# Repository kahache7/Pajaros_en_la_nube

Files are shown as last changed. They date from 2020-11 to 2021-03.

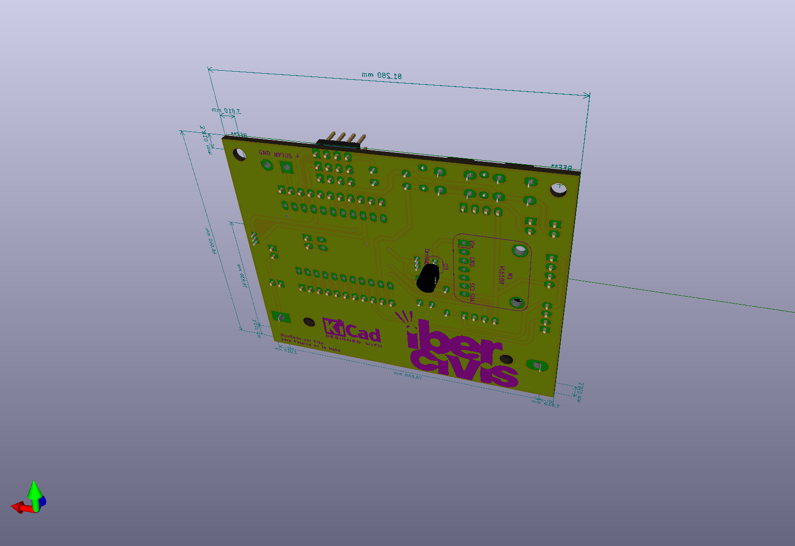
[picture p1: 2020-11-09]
Electronica/Fotos/AdaptaddorCubeCell3.png

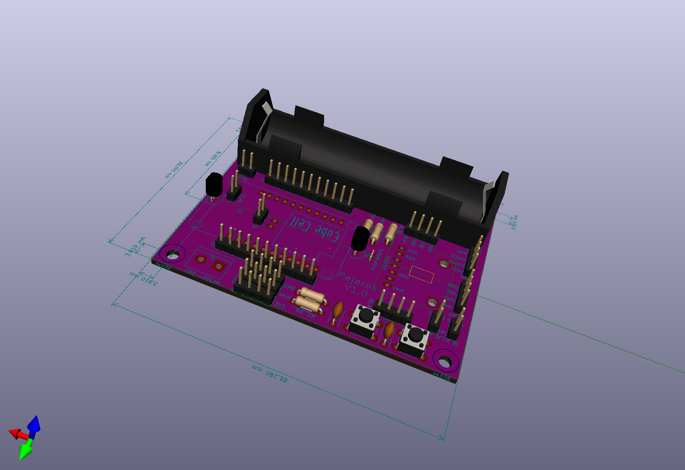
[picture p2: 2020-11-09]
Electronica/Fotos/AdaptaddorCubeCell.png

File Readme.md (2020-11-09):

# Pájaros en la Nube

El proyecto Pájaros en la Nube tiene como objetivo monitorizar la fauna insectívora en todo el país, a través del desarrollo de un proyecto multidisciplinar que abarca diversas áreas del conocimiento científico y tecnológico, e involucrando a miles de estudiantes de centros de educación de primaria y secundaria.

Temas como la conservación de la biodiversidad, la ornitología, el internet de las cosas (IoT, por sus siglas en Inglés, Internet of Things), la computación en la nube, arduino, programación, matemáticas, meteorología y ciencia ciudadana (CC) se unen de forma consistente en un único proyecto.

Fundación Ibercivis FeCyT

### Mecánica del Proyecto
Durante el curso 2020/21 se colaborará con 100 centros educativos de todo el país que recibirán -sin coste alguno- los materiales para ensamblar y sensorizar una caseta de pájaros que, tras su montaje, será colocada en las inmedicaiones del centro.

La observación de esta caseta y los datos que entregarán sus sensores –presencia de animales en ella y temperatura– servirá para que los alumnos conozcan y estudien la fauna insectívora que les rodea -principalmente aves, pero también pequeños reptiles, murciélagos…-.

Además, como parte del trabajo inicial de montaje de la caseta, los alumnos aprenderán a programar en arduino para controlar sus sensores, y adquirirán nociones de física, matemáticas o meteorología.

El envío de datos desde la caseta al aula se hará a través de la tecnología LoRaWAN diseñada específicamente para dispositivos de bajo consumo de alimentación, que operan en redes de alcance local, regional, nacionales o globales. Este montaje convierte a la caseta en un dispositivo conectado al Internet de las Cosas (IOT).

* Start object:
```void begin(pinRX,pinTX);```

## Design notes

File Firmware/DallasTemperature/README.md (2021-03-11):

Modificaciones para el fichero DallasTemperature.cpp de la version 3.9

Sustituir yield() por delay(0) para que compile bien en cubecell

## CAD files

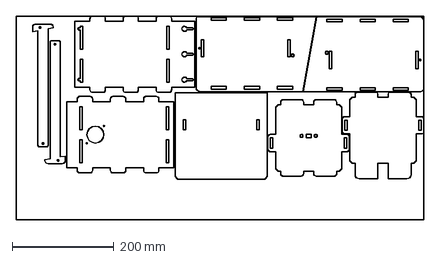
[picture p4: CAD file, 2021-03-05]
Caseta/laser_5mm_v3.dxf
800.0 x 400.2 mm

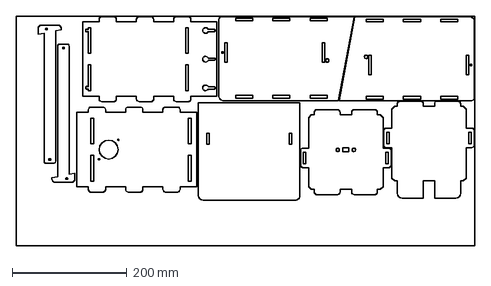
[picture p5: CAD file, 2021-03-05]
Caseta/laser_4.5mm_v3_zgz.dxf
800.0 x 400.0 mm

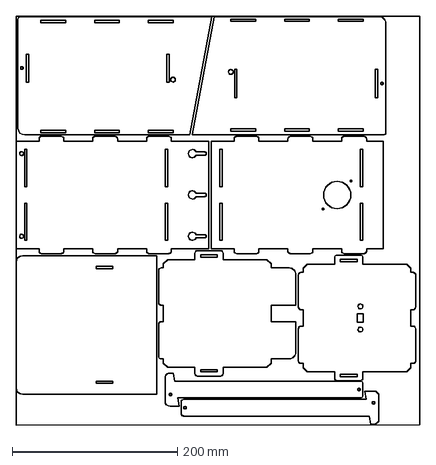
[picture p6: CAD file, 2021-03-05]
Caseta/laser_2.9mm_v3.dxf
488.3 x 494.4 mm

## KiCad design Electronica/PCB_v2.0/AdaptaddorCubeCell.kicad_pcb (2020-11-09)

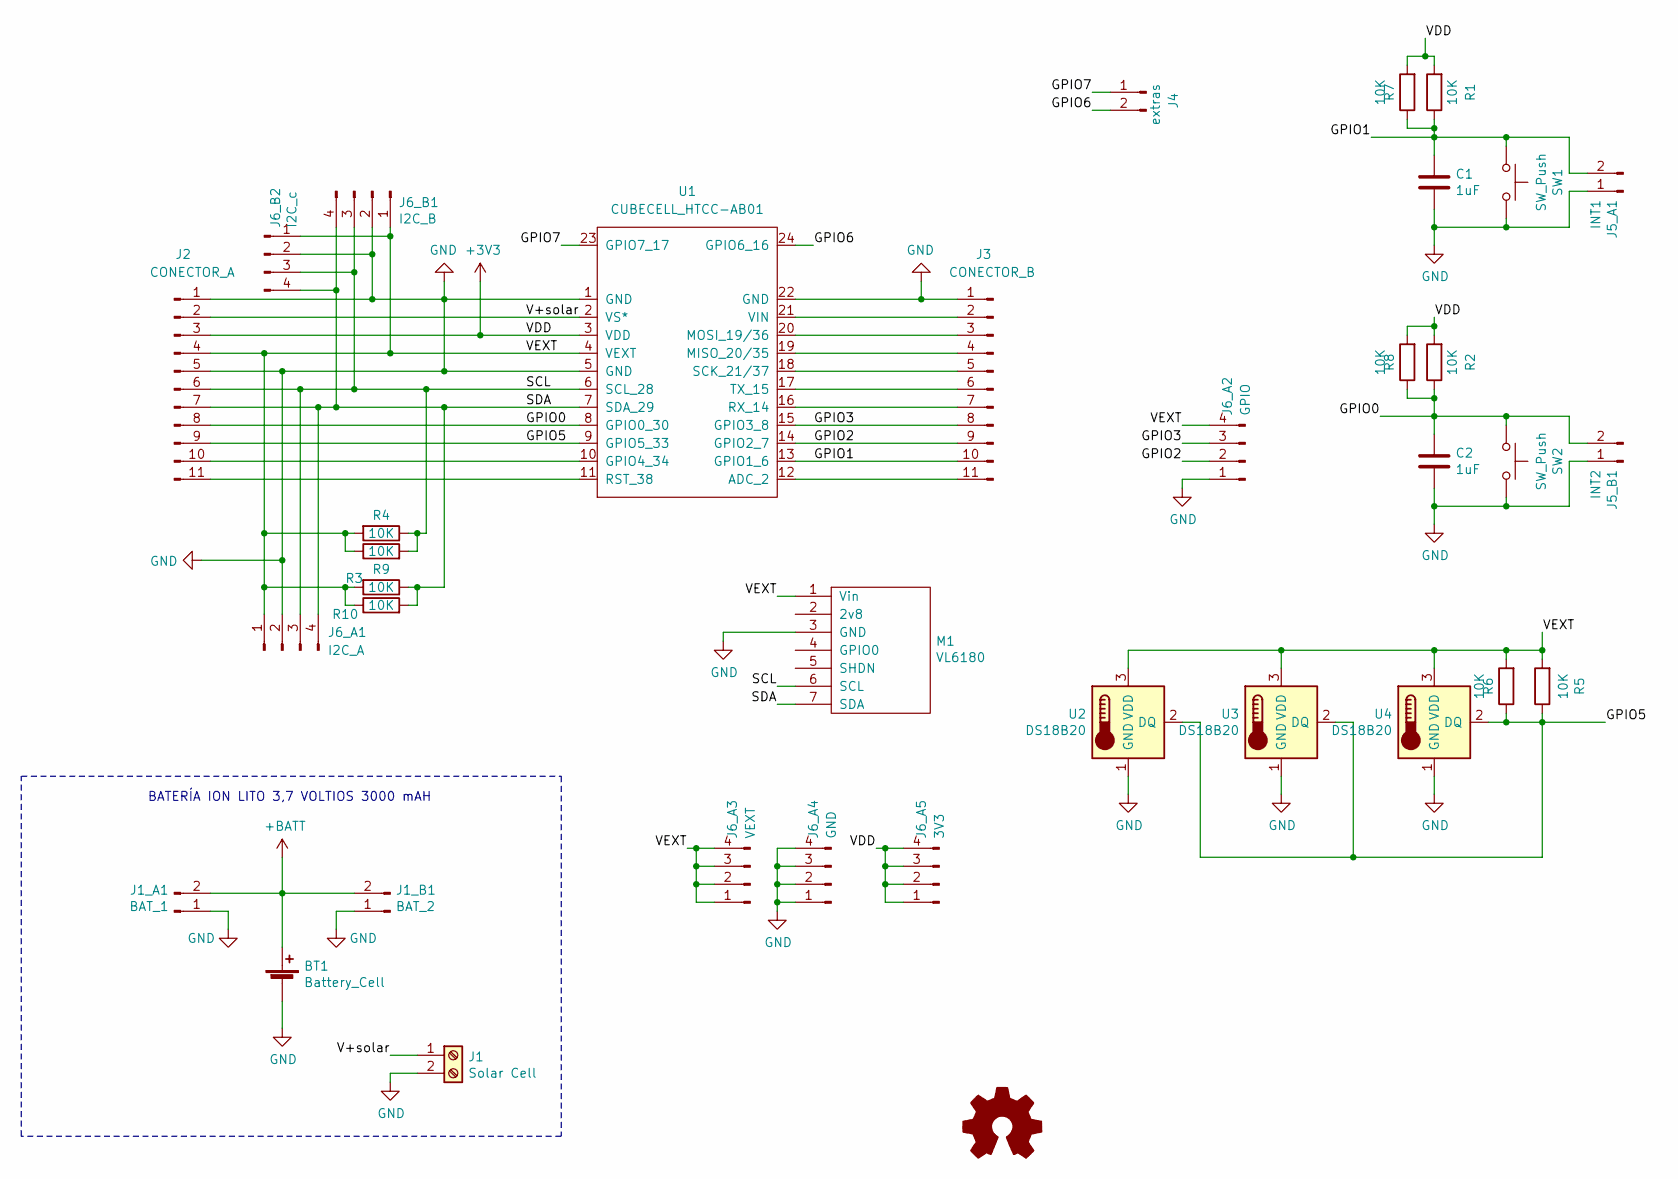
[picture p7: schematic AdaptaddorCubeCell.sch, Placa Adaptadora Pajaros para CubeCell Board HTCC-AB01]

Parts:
BT1: Battery_Cell; BatteryHolder_MPD_BH-18650-PC2
C1, C2: 1uF; C_Disc_D5.0mm_W2.5mm_P5.00mm
J1: Solar Cell; TerminalBlock_bornier-2_P5.08mm
J1_A1: BAT_1; PinHeader_1x02_P2.54mm_Vertical_custom
J1_B1: BAT_2; PinHeader_1x02_P2.54mm_Vertical_custom
J2: CONECTOR_A; PinHeader_1x11_P2.54mm_Vertical
J3: CONECTOR_B; PinHeader_1x11_P2.54mm_Vertical
J4: extras; PinHeader_1x02_P2.54mm_Vertical_custom
J5_A1: INT1; PinHeader_1x02_P2.54mm_Vertical_custom
J5_B1: INT2; PinHeader_1x02_P2.54mm_Vertical_custom
J6_A1: I2C_A; PinHeader_1x04_P2.54mm_Vertical
J6_A2: GPIO; PinHeader_1x04_P2.54mm_Vertical
J6_A3: VEXT; PinHeader_1x04_P2.54mm_Vertical
J6_A4: GND; PinHeader_1x04_P2.54mm_Vertical
J6_A5: 3V3; PinHeader_1x04_P2.54mm_Vertical
J6_B1: I2C_B; PinHeader_1x04_P2.54mm_Vertical
J6_B2: I2C_c; PinHeader_1x04_P2.54mm_Vertical
M1: VL6180; VL6180x
R1, R2, R3, R4, R5: 10K; R_Axial_DIN0207_L6.3mm_D2.5mm_P7.62mm_Horizontal
R6, R7, R8, R9, R10: 10K; R_1206_HandSoldering
SW1, SW2: SW_Push; SW_PUSH_6mm_H5mm
U1: CUBECELL_HTCC-AB01; CubeCell_HTCC-AB01
U2, U3, U4: DS18B20; TO-92_Inline_Narrow_Oval

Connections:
+3V3: J2.3, J6_A5.1, J6_A5.2, J6_A5.3, J6_A5.4, R1.2, R2.2, R7.2, R8.2, U1.3 (VDD)
+BATT: BT1.1 (+), J1_A1.2, J1_B1.2
/GPIO0: C2.1, J2.8, J5_B1.2, R2.1, R8.1, SW2.1, U1.8 (GPIO0_30)
/GPIO1: C1.1, J3.10, J5_A1.2, R1.1, R7.1, SW1.1, U1.13 (GPIO1_6)
/GPIO2: J3.9, J6_A2.2, U1.14 (GPIO2_7)
/GPIO3: J3.8, J6_A2.3, U1.15 (GPIO3_8)
/GPIO5: J2.9, R5.1, R6.1, U1.9 (GPIO5_33), U2.2 (DQ), U3.2 (DQ), U4.2 (DQ)
/GPIO6: J4.2, U1.24 (GPIO6_16)
/GPIO7: J4.1, U1.23 (GPIO7_17)
/SCL: J2.6, J6_A1.3, J6_B1.3, J6_B2.3, M1.6 (SCL), R4.1, R9.2, U1.6 (SCL_28)
/SDA: J2.7, J6_A1.4, J6_B1.4, J6_B2.4, M1.7 (SDA), R3.1, R10.2, U1.7 (SDA_29)
/V+solar: J1.1, J2.2, U1.2 (VS*)
/VEXT: J2.4, J6_A1.1, J6_A2.4, J6_A3.1, J6_A3.2, J6_A3.3, J6_A3.4, J6_B1.1, J6_B2.1, M1.1 (Vin), R3.2, R4.2, R5.2, R6.2, R9.1, R10.1, U1.4 (VEXT), U2.3 (VDD), U3.3 (VDD), U4.3 (VDD)
GND: BT1.2 (-), C1.2, C2.2, J1.2, J1_A1.1, J1_B1.1, J2.1, J2.5, J3.1, J5_A1.1, J5_B1.1, J6_A1.2, J6_A2.1, J6_A4.1, J6_A4.2, J6_A4.3, J6_A4.4, J6_B1.2, J6_B2.2, M1.3 (GND), SW1.2, SW2.2, U1.1 (GND), U1.5 (GND), U1.22 (GND), U2.1 (GND), U3.1 (GND), U4.1 (GND)
unnamed: J2.10, U1.10 (GPIO4_34)
unnamed: J2.11, U1.11 (RST_38)
unnamed: J3.2, U1.21 (VIN)
unnamed: J3.3, U1.20 (MOSI_19/36)
unnamed: J3.4, U1.19 (MISO_20/35)
unnamed: J3.5, U1.18 (SCK_21/37)
unnamed: J3.6, U1.17 (TX_15)
unnamed: J3.7, U1.16 (RX_14)
unnamed: J3.11, U1.12 (ADC_2)

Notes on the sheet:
BATERÍA ION LITO 3,7 VOLTIOS 3000 mAH

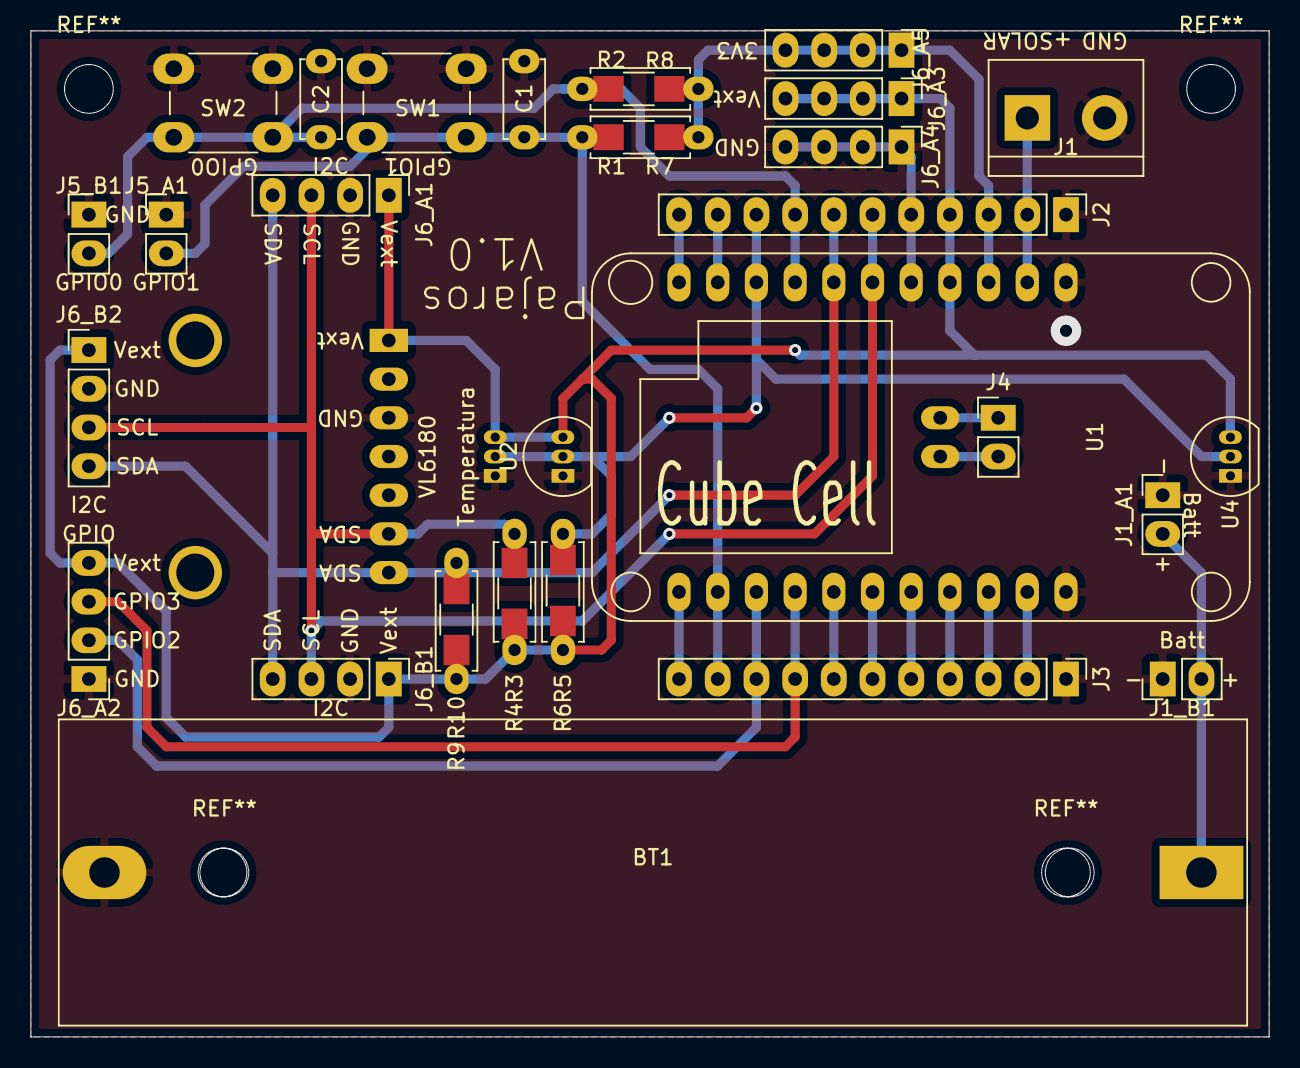
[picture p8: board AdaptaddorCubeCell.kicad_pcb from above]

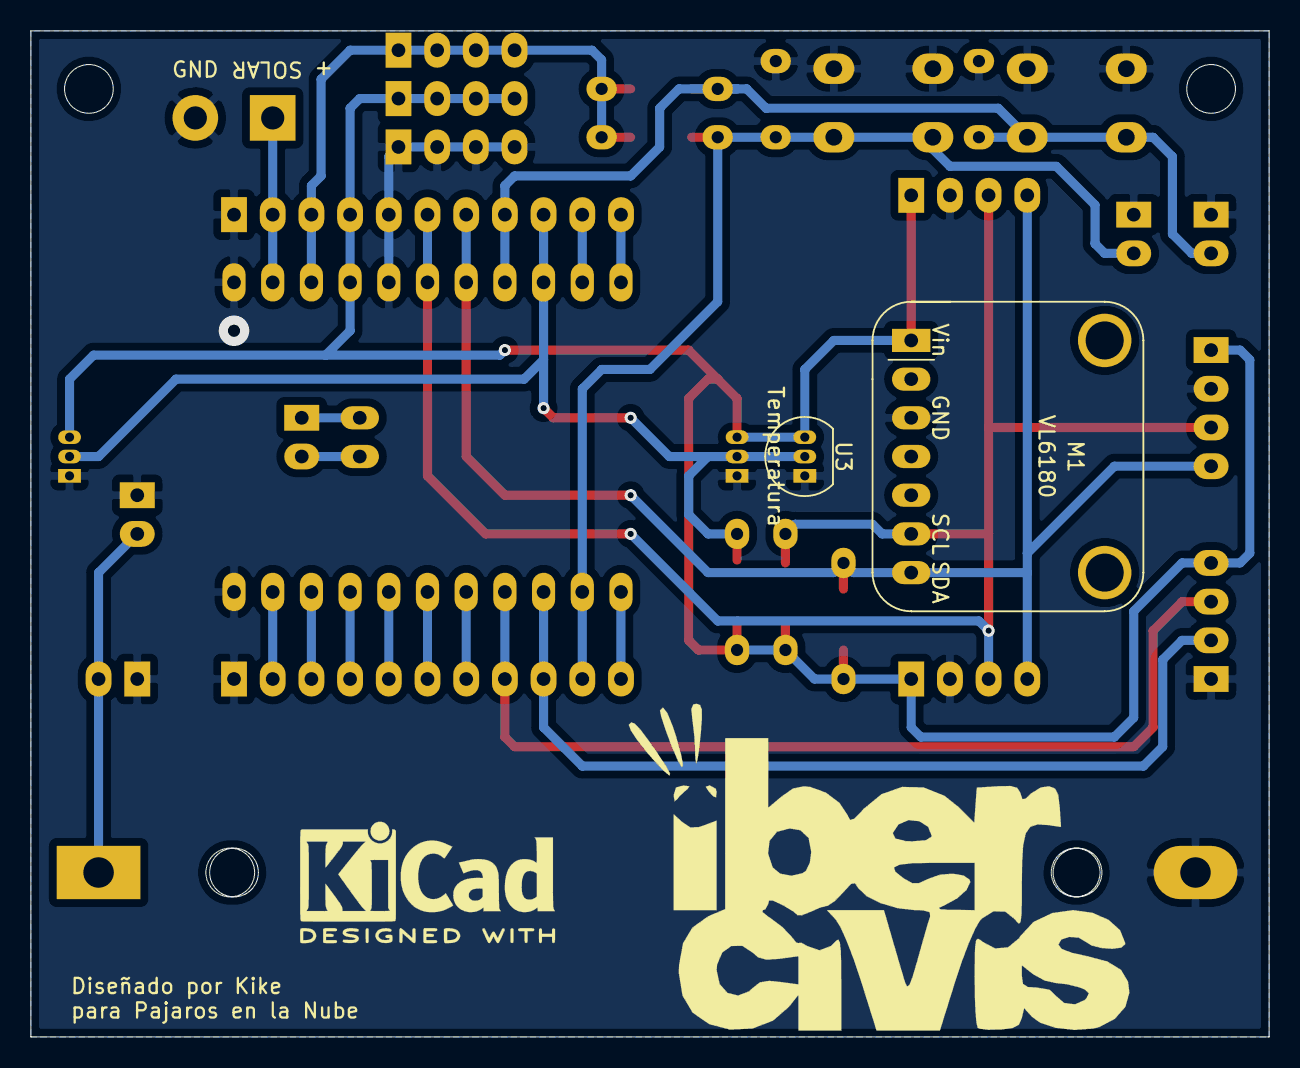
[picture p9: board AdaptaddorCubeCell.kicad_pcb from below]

Board: 2 copper layers, 81.3 x 66.0 mm, 35 parts (2 on the bottom side), 23 nets.

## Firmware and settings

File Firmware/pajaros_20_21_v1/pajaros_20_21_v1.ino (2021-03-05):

/*
 *  Pajaros en la nube V2.0 beta
 *  Author: Enrique Torres enrique.torres@unizar.es 
 *  Based on code from the examples, mixing lowpower wakeup by timer and LoRAWAN 
 *  region EU868,Class A, ABP, Unconfirmed, AT support off (save power)
 *  RGB active? no to save power, on for debug
 *  
 *  Dependencies: Adafruit VL6180x
 *  
 *  LoRAWan_APP, onewire and dallastemperature from Heltech framework (last framework, bug in previous)
 */
 
#include "LoRaWan_APP.h"
#include "Arduino.h"

//kike
  #include <Wire.h>
  #include "Adafruit_VL6180X.h"

  #include <OneWire.h> //kike lib renamed from the cubecell repositorie with conflict with my other onewire lib
  #include <DallasTemperature.h>

  enum constants{
    // Data wire is plugged into GPIO5 on the CubeCell
    ONE_WIRE_BUS          = GPIO5,
    NUM_DS18b20           = 3,
    TEMPERATURE_PRECISION = 12, //kike ideal 9 por compromiso precision tiempo de conversion, pero como le cuesta a la ds18b20 china lo mismo 9 que 12...
    INTERVALO_TX = 10 * 60 * 1000 //kike 10 mitutos entre transmisiones en ms
  };

  #define SHOW_DEBUGINFO
  #ifdef SHOW_DEBUGINFO
    #define BAUD_SERIAL 115200
    #define debugSerial Serial
    #define debugPrintln(...) { if (debugSerial) debugSerial.println(__VA_ARGS__); }
    #define debugPrint(...) { if (debugSerial) debugSerial.print(__VA_ARGS__); }
    #define debugPrintf(...) { if (debugSerial) debugSerial.printf(__VA_ARGS__); }
    #define debugPrintfln(...) { if (debugSerial) debugSerial.printf(__VA_ARGS__); debugSerial.println("");}
  #else
    #define debugSerial null
    #define debugPrintln(...) {}
    #define debugPrint(...) {}
    #define debugPrintf(...) {}
    #define debugPrintfln(...) {}  
  #endif
// /kike

/*
 * set LoraWan_RGB to Active,the RGB active in loraWan
 * RGB red means sending;
 * RGB purple means joined done;
 * RGB blue means RxWindow1;
 * RGB yellow means RxWindow2;
 * RGB green means received done;
 */

////////
// LoRaWAN
  #include "lora_keys.h" //kike lora ABP app sesion key, network sesion key and device address

  /* OTAA para*/
  uint8_t devEui[] = { 0x22, 0x32, 0x33, 0x00, 0x00, 0x88, 0x88, 0x02 };
  uint8_t appEui[] = { 0x00, 0x00, 0x00, 0x00, 0x00, 0x00, 0x00, 0x00 };
  uint8_t appKey[] = { 0x88, 0x88, 0x88, 0x88, 0x88, 0x88, 0x88, 0x88, 0x88, 0x88, 0x88, 0x88, 0x88, 0x88, 0x66, 0x01 };
  
  /* ABP para*/
  //kike se cogen del fichero lora_key.h
  // dentro solo tiene algo del estilo a:
  //  /* ABP para*/
  //uint8_t mynwkSKey[] = { clave de sesion de red };
  //uint8_t myappSKey[] = { clave de sesion de la app };
  //uint32_t mydevAddr =  ( uint32_t )0xdexaddr del dispositivo;
  uint8_t nwkSKey[] = { 0x88, 0x88, 0x88, 0x88, 0x88, 0x88, 0x88, 0x88, 0x88, 0x88, 0x88, 0x88, 0x88, 0x88, 0x66, 0x01 };
  uint8_t appSKey[] = { 0x88, 0x88, 0x88, 0x88, 0x88, 0x88, 0x88, 0x88, 0x88, 0x88, 0x88, 0x88, 0x88, 0x88, 0x66, 0x01 };
  uint32_t devAddr =  ( uint32_t )0x26011881; 

  /*LoraWan channelsmask, default channels 0-7*/ 
  uint16_t userChannelsMask[6]={ 0x00FF,0x0000,0x0000,0x0000,0x0000,0x0000 }; //kike default channels 0..7
  //uint16_t userChannelsMask[6]={ 0x0001,0x0000,0x0000,0x0000,0x0000,0x0000 }; //kike channel cero only to support ABP one channel gateways
  
  /*LoraWan region, select in arduino IDE tools*/
  LoRaMacRegion_t loraWanRegion = ACTIVE_REGION;
  
  /*LoraWan Class, Class A and Class C are supported*/
  DeviceClass_t  loraWanClass = LORAWAN_CLASS;
  
  /*the application data transmission duty cycle.  value in [ms].*/
  //uint32_t appTxDutyCycle = 15000;
  uint32_t appTxDutyCycle = INTERVALO_TX; //kike ms entre transmisiones
  
  /*OTAA or ABP*/
  bool overTheAirActivation = LORAWAN_NETMODE;
  
  /*ADR enable*/
  bool loraWanAdr = LORAWAN_ADR;
  
  /* set LORAWAN_Net_Reserve ON, the node could save the network info to flash, when node reset not need to join again */
  bool keepNet = LORAWAN_NET_RESERVE;
  
  /* Indicates if the node is sending confirmed or unconfirmed messages */
  bool isTxConfirmed = LORAWAN_UPLINKMODE;
  
  /* Application port */
  uint8_t appPort = 2;
  /*!
  * Number of trials to transmit the frame, if the LoRaMAC layer did not
  * receive an acknowledgment. The MAC performs a datarate adaptation,
  * according to the LoRaWAN Specification V1.0.2, chapter 18.4, according
  * to the following table:
  *
  * Transmission nb | Data Rate
  * ----------------|-----------
  * 1 (first)       | DR
  * 2               | DR
  * 3               | max(DR-1,0)
  * 4               | max(DR-1,0)
  * 5               | max(DR-2,0)
  * 6               | max(DR-2,0)
  * 7               | max(DR-3,0)
  * 8               | max(DR-3,0)
  *
  * Note, that if NbTrials is set to 1 or 2, the MAC will not decrease
  * the datarate, in case the LoRaMAC layer did not receive an acknowledgment
  */
  uint8_t confirmedNbTrials = 4;

///////
// sensors
 
  // Setup a oneWire instance to communicate with any OneWire devices (not just Maxim/Dallas temperature ICs)
  OneWire oneWire(ONE_WIRE_BUS);
  
  // Pass our oneWire reference to Dallas Temperature.
  DallasTemperature sensors(&oneWire);
  
  // arrays to hold device addresses
  DeviceAddress DS18b20_0, DS18b20_1, DS18b20_2;


  // TimeOfFlight //kike altura del nido
  Adafruit_VL6180X ToF = Adafruit_VL6180X();

//////
// ToF

  void ToF_init(){
    if (! ToF.begin()) {
      debugPrintln("Failed to find sensor");
      //kike TODO retry? no seguir?
      //while ( xxxx && count < maxtry) { count++ ...
    }
  }
  
  uint8_t VL6180X_leer(){
    ToF_init(); //kike TODO es necesario el begin cada vez que salgamos de powerdown?
    
    uint8_t range = ToF.readRange();
    uint8_t status = ToF.readRangeStatus();
    Wire.end();
    
    if (status == VL6180X_ERROR_NONE) {
      debugPrint("VL6180X Range: "); debugPrint(range);
    }

    #ifdef SHOW_DEBUGINFO
      // Some error occurred, print it out!   
      if  ((status >= VL6180X_ERROR_SYSERR_1) && (status <= VL6180X_ERROR_SYSERR_5)) {
        debugPrintln("System error");
      }
      else if (status == VL6180X_ERROR_ECEFAIL) {
        debugPrintln("ECE failure");
      }
      else if (status == VL6180X_ERROR_NOCONVERGE) {
        debugPrintln("No convergence");
      }
      else if (status == VL6180X_ERROR_RANGEIGNORE) {
        debugPrintln("Ignoring range");
      }
      else if (status == VL6180X_ERROR_SNR) {
        debugPrintln("Signal/Noise error");
      }
      else if (status == VL6180X_ERROR_RAWUFLOW) {
        debugPrintln("Raw reading underflow");
      }
      else if (status == VL6180X_ERROR_RAWOFLOW) {
        debugPrintln("Raw reading overflow");
      }
      else if (status == VL6180X_ERROR_RANGEUFLOW) {
        debugPrintln("Range reading underflow");
      }
      else if (status == VL6180X_ERROR_RANGEOFLOW) {
        debugPrintln("Range reading overflow");
      }
    #endif
    
    return range;
  }
  
///////////
// ds18b20
 
  void printAddress(DeviceAddress deviceAddress){
    #ifdef SHOW_DEBUGINFO 
      for (uint8_t i = 0; i < 8; i++)
      {
        debugPrint("0x");
        if (deviceAddress[i] < 0x10) debugPrint("0");
        debugPrint(deviceAddress[i], HEX);
        if (i < 7) debugPrint(", ");
      }
      debugPrintln("");
   #endif 
  }

  void DS18b20_init(){
    uint8_t num_detected;

    oneWire.reset_search();
    
    sensors.begin();

    //kike todo pensar los retry count = 0;
    debugPrintln("");
    debugPrintln("DS18b20:");
    // locate devices on the bus
    debugPrint("Locating devices...");
    num_detected = sensors.getDeviceCount();
    debugPrintfln("Found %d devices.", num_detected);

    if (num_detected != NUM_DS18b20){
      debugPrintfln("ERROR: se eseraban %d", NUM_DS18b20); 
    }
    
    // report parasite power requirements
    debugPrint("Parasite power is: ");
    if (sensors.isParasitePowerMode()) {debugPrintln("ON");} //kike TODO algo pasa con las macros y las {}
    else debugPrintln("OFF");
  
    // Search for devices on the bus and assign based on an index. Ideally,
    // you would do this to initially discover addresses on the bus and then
    // use those addresses and manually assign them (see above) once you know
    // the devices on your bus (and assuming they don't change).
    //
    // method 1: by index 
    debugPrintln("Printing addresses...");
    
    if (!sensors.getAddress(DS18b20_0, 0)){
      debugPrint("Unable to find address for Device ");
      debugPrintln(0);
    } else {
      debugPrintf("Sensor %d: ",0);
      printAddress(DS18b20_0);
    }
    //kike TODO hacer array de adress y no replicar!!
    if (!sensors.getAddress(DS18b20_1, 1)){
      debugPrint("Unable to find address for Device ");
      debugPrintln(1);
    } else {
      debugPrintf("Sensor %d: ",1);
      printAddress(DS18b20_1);
    }
    if (!sensors.getAddress(DS18b20_2, 2)){
      debugPrint("Unable to find address for Device ");
      debugPrintln(2);
    } else {
      debugPrintf("Sensor %d: ",2);
      printAddress(DS18b20_2);
    }
    
    // set the resolution to n bit per device
    sensors.setResolution(DS18b20_0, TEMPERATURE_PRECISION);
    sensors.setResolution(DS18b20_1, TEMPERATURE_PRECISION);
    sensors.setResolution(DS18b20_2, TEMPERATURE_PRECISION);

    #ifdef SHOW_DEBUGINFO
      debugPrintfln("Resoluccion Sensor %d: %d", 0, sensors.getResolution(DS18b20_0));
      debugPrintfln("Resoluccion Sensor %d: %d", 1, sensors.getResolution(DS18b20_1));
      debugPrintfln("Resoluccion Sensor %d: %d", 2, sensors.getResolution(DS18b20_2));
    #endif
  }
  
  void DS18b20_leer(float temperatura[NUM_DS18b20]){
    //kike TODO se puede no pasar por el begin cada vez que se vuelva de power down??? 
//    oneWire.reset(); //    

    sensors.begin();  //kike en main DS18b20_init();

    //kike TODO lectura asyncrona?????
    sensors.requestTemperatures();
//    delay(120);
    
    temperatura[0] = sensors.getTempC(DS18b20_0);
    temperatura[1] = sensors.getTempC(DS18b20_1);
    temperatura[2] = sensors.getTempC(DS18b20_2);

    #ifdef SHOW_DEBUGINFO
      debugPrintln();
      debugPrint("DS18b20:");
      for (int i = 0; i< NUM_DS18b20;i++){
        debugPrintf(" Temp C%d: ", i);
        debugPrint(temperatura[i]);
      }
      debugPrintln();
    #endif
  }

  void DS18b20_leer_asyn_start(){
   sensors.begin();  //kike en main DS18b20_init();

   //kike peticion asyncrona
   sensors.setWaitForConversion(false);
   sensors.requestTemperatures();
//   sensors.setWaitForConversion(true);    
  }
  
  void DS18b20_leer_asyn(float temperatura[NUM_DS18b20]){
    //kike si aun no ha terminado de convertir... esperar
    while(!sensors.isConversionComplete()){
      #ifdef SHOW_DEBUGINFO      
        debugPrint(".");
      #endif
      delay(50);
    }

    temperatura[0] = sensors.getTempC(DS18b20_0);
    temperatura[1] = sensors.getTempC(DS18b20_1);
    temperatura[2] = sensors.getTempC(DS18b20_2);
  }
  
// kike ******* fin sondas

/* Prepares the payload of the frame */
static void prepareTxFrame( uint8_t port )
{
	/*appData size is LORAWAN_APP_DATA_MAX_SIZE which is defined in "commissioning.h".
	*appDataSize max value is LORAWAN_APP_DATA_MAX_SIZE.
	*if enabled AT, don't modify LORAWAN_APP_DATA_MAX_SIZE, it may cause system hanging or failure.
	*if disabled AT, LORAWAN_APP_DATA_MAX_SIZE can be modified, the max value is reference to lorawan region and SF.
	*for example, if use REGION_CN470, 
	*the max value for different DR can be found in MaxPayloadOfDatarateCN470 refer to DataratesCN470 and BandwidthsCN470 in "RegionCN470.h".
	*/

  float temperatura[NUM_DS18b20];
  
  pinMode(Vext, OUTPUT);
  digitalWrite(Vext, LOW);
  delay(50); //kike retardo para asentar Vext. Era 500 para bme280, en el ejempplo del VL6180x 50

  DS18b20_leer_asyn_start();

  #ifdef SHOW_DEBUGINFO
    debugPrintln();
    debugPrintln("********** Formando nueva trama **********");
    debugPrintln();
  #endif

  uint8_t altura_nido = VL6180X_leer();
  debugPrintln();

  uint16_t voltage = getBatteryVoltage();

  #ifdef SHOW_DEBUGINFO
    debugPrintln();
    debugPrintfln("Bateria mV: %d", voltage);
    debugPrintln();
  #endif
  
  //kike aun convirtiendo las lentas temperauras, seguro... adelantar trabajo
  appDataSize = 9;    
  appData[0] = highByte(voltage); //(uint8_t)(voltage >> 8)
  appData[1] = lowByte(voltage);  //(uint8_t)voltage

  appData[2] = altura_nido;

  DS18b20_leer_asyn(temperatura); 

  //kike power off lo antes posible
  digitalWrite(Vext, HIGH);

  #ifdef SHOW_DEBUGINFO
    debugPrintln();
    debugPrint("DS18b20:");
    for (int i = 0; i< NUM_DS18b20;i++){
      debugPrintf(" Temp C%d: ", i);
      debugPrint(temperatura[i]);
    }
    debugPrintln();
  #endif
  
  for (int i = 0; i< NUM_DS18b20;i++){
    int16_t itemp = int16_t(temperatura[i] * 100);

    if (itemp < 0){
        itemp *= -1;
        itemp |= 0x8000;
    }
    appData[3 + (i * 2)] = highByte(itemp); //(uint8_t)(voltage >> 8)
    appData[4 + (i * 2)] = lowByte(itemp);  //(uint8_t)voltage
  }

//kike TTN decoder at the end of code
}

/* //kike del ejemplo de downlink por si se desea bidireccionalidad...
//downlink data handle function example
void downLinkDataHandle(McpsIndication_t *mcpsIndication)
{
  Serial.printf("+REV DATA:%s,RXSIZE %d,PORT %d\r\n",mcpsIndication->RxSlot?"RXWIN2":"RXWIN1",mcpsIndication->BufferSize,mcpsIndication->Port);
  Serial.print("+REV DATA:");
  for(uint8_t i=0;i<mcpsIndication->BufferSize;i++)
  {
    Serial.printf("%02X",mcpsIndication->Buffer[i]);
  }
  Serial.println();
  uint32_t color=mcpsIndication->Buffer[0]<<16|mcpsIndication->Buffer[1]<<8|mcpsIndication->Buffer[2];
#if(LoraWan_RGB==1)
  turnOnRGB(color,5000);
  turnOffRGB();
#endif
}
*/

void setup() {

  //copy credenciales de lora_keys.h
    memcpy(nwkSKey, (void*)mynwkSKey, sizeof(mynwkSKey)); //copy keys from .h
    memcpy(appSKey, (void*)myappSKey, sizeof(myappSKey));
    devAddr = mydevAddr; //es un uint32 memcpy(devAddr, (void*)mydevAddr, sizeof(mydevAddr));

  
	boardInitMcu();

  #ifdef SHOW_DEBUGINFO
	  Serial.begin(BAUD_SERIAL);
  #endif
  
  uint64_t chipID=getID();
  debugPrintf("ChipID: %04X%08X\r\n",(uint32_t)(chipID>>32),(uint32_t)chipID);

  pinMode(Vext, OUTPUT);
  digitalWrite(Vext, LOW);
  delay(500); //kike era 500 para bme280, en el ejempplo del VL6180x 50. Esta en setup, solo se hace la primera vez.

  DS18b20_init(); //kike get ds18b20 address
  
  digitalWrite(Vext, HIGH);
  
  
#if(AT_SUPPORT)
	enableAt();
#endif

	deviceState = DEVICE_STATE_INIT;
	LoRaWAN.ifskipjoin();
}

void loop()
{
	switch( deviceState )
	{
		case DEVICE_STATE_INIT:
		{
#if(AT_SUPPORT)
			getDevParam();
#endif
			printDevParam();
			LoRaWAN.init(loraWanClass,loraWanRegion);
			deviceState = DEVICE_STATE_JOIN;
			break;
		}
		case DEVICE_STATE_JOIN:
		{
			LoRaWAN.join();
			break;
		}
		case DEVICE_STATE_SEND:
		{
			prepareTxFrame( appPort );
			LoRaWAN.send();
			deviceState = DEVICE_STATE_CYCLE;
			break;
		}
		case DEVICE_STATE_CYCLE:
		{
			// Schedule next packet transmission
			txDutyCycleTime = appTxDutyCycle + randr( 0, APP_TX_DUTYCYCLE_RND );
			LoRaWAN.cycle(txDutyCycleTime);
			deviceState = DEVICE_STATE_SLEEP;
			break;
		}
		case DEVICE_STATE_SLEEP:
		{
			LoRaWAN.sleep();
			break;
		}
		default:
		{
			deviceState = DEVICE_STATE_INIT;
			break;
		}
	}
}

//DECODER FUNCTION FOR TTN
/* 
function Decoder(bytes, port) {
  // Decode an uplink message from a buffer
  // (array) of bytes to an object of fields.
  var decoded = {};

  if (port === 2) {
    decoded.batt = bytes[0]<<8 | bytes[1];
    if (decoded.batt === 0)
       delete decoded.batt; 
    
    decoded.altura = bytes[2];
    
    var celciusInt = bytes[4] | (bytes[3] << 8);

    if (celciusInt & 0x8000) celciusInt = (celciusInt & 0x7fff) * -1;
    decoded.tempC1 = celciusInt / 100;
    
    celciusInt = bytes[6] | (bytes[5] << 8);

    if (celciusInt & 0x8000) celciusInt = (celciusInt & 0x7fff) * -1;
    decoded.tempC2 = celciusInt / 100;

    celciusInt = bytes[8] | (bytes[7] << 8);
    
    if (celciusInt & 0x8000) celciusInt = (celciusInt & 0x7fff) * -1;
    decoded.tempC3 = celciusInt / 100;    
  }
  return decoded;
}
*/

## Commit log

2020-11-09 primer version
    [Adafruit VL6180Xa_2020-10-10_11-27-47.kicad_pcb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]
2021-03-05 Create pajaros en la nube logo_trazos.svg
2021-03-05 Create Adafruit VL6180Xa_2020-10-10_11-27-47.kicad_pcb
    [Adafruit VL6180Xa_2020-10-10_11-27-47.kicad_pcb]
